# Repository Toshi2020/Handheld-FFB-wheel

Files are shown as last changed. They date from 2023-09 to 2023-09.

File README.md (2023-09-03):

# Handheld-FFB-wheel  
# ハンドヘルド型FFB(フォースフィードバック)ハンドルコントローラー  

**●ここには詳細を置きます。概要はこちら↓に記述しました。**  
https://minkara.carview.co.jp/userid/3336538/blog/47191094/

**動作の状況の動画はこちら。**  
https://youtu.be/O-O_uvx_jfw 

**●初めに**  
　PCで車のゲームをプレイするとき、ゲームパッドではハンドル操作感が乏しいので運転が難しく、かといって机にFFBハンドルコントローラーを据え付けると使わないときに邪魔です。そこで気が向いた時だけ手軽に接続できるようにハンドヘルド型FFBハンドルコントローラーを作ってみました。  
外観

**●主な部品**  
①DCモーター: タミヤ ソーラーモーター02 Amazon購入価格 721円  
②Arduino Pro Micro: AliExpress購入価格 568円  
③モータードライバー: BD6211F-E2 秋月購入価格 110円  
④ピッチ変換基板: P-05154 秋月購入価格 100円/9枚 単価11円  
⑤ショットキーバリアダイオード: 1S4 秋月購入価格 140円/10本 単価14円  
⑥ツェナーダイオード: Amazonでアソートキット 1200円/200本 単価6円  
⑦ボリューム: Bカーブ 手持ち品ですが秋月では60円  
⑧タクトスイッチ: 昔秋月で購入した手持ち品ですが今は 300円/10個 単価30円x3  
⑨分割ロングピンソケット: 秋月購入価格 80円  
⑩ジョイスティック: Amazon購入価格 799円/5個 単価160円  
その他は手持ちから流用ですが全部購入してもトータルで2,000円弱かと思います。(3Dプリンタのフィラメント代が別途必要です。)  
パーツ

**●ハードウェア**  
回路図2

メインボード

・マイコンボードとしてArduino Pro Microを使います。PC用ゲームコントローラとして使うためにはArduino NANOやArduino Pro Miniではダメなので注意が必要です。今回AliexpressからUSB Type-Cコネクタの物を調達しました。  
・Arduinoは他に転用するかもしれないので秋月の分割ロングピンソケットを介して万能基板に取り付けて、ずれないように4隅をホットボンドで固定しています。またUSBコネクタ部分もホットボンドで補強しています。それとArduinoのピンは付属品ではなく秋月の細ピンヘッダ―を使っています。  
メインボード2

・USB給電だけで動かしたかったので、反力用のモーターとしては小電流で低回転のタミヤのソーラーモーター02を使います。このモーター、ネットで調べたのですが詳細スペックがわからず、おそらくAmazonで売られているRF-500TB-18280という型番の物ではないかと思います。タミヤで出している物は価格が少し高いのですがM2.5(?)の取り付けネジとピニオンギアが同梱されているのがメリットです。  
・モータードライバは秋月で購入したBD6211F-E2を同じく秋月のピッチ変更基板を使って組んでいます。  
・モーターを外部から回転させることになるので逆起電力により、モーターの回転と同方向に回すと供給電圧以上の電圧が発生し、逆方向に回すとストール電流以上の電流が流れるはずです(実測はしていないのですが)。マイコンやPCのUSB側に過電圧がかからないように1Aのショットキーダイオード1S4を介してモーターとドライバに給電しています。またドライバの定格電圧が7Vなので、保護のために5.6V 1Wのツェナーダイオードを入れています。電源ラインには100μの電解コンデンサを入れて電圧ドロップに対応したつもりです。  
・ボリュームは手持ちの関係でB型50kΩを使いましたがB型なら1k～100kΩの範囲で大丈夫だと思います。10kΩが良いかと思います。  
・ジョイスティックは、当初前後に倒してアクセル/ブレーキ、左右に倒してスイッチ(シフトアップ/シフトダウンに割り当て)としたのですが、操作に難があることがわかりY軸のみを使うことにしました。前後に倒したつもりでも左右に動いてしまうので、アクセル/ブレーキの微妙な調整が難しいのです。  
・パーツやケースの上下の固定はM3の6mmのビスを使用します。  
・モーターのシャフトには10歯のピニオンギアを使います。  
・モーターとボリュームは振動するのでネジロック剤を併用して取り付けています。  
・モーター、ボリューム、スイッチは万能基板とXHコネクタで接続しています。何度か抜き差ししているうちにコネクタの付け根が断線してしまったのでホットボンドで補強しています。  
内部

**●ソフトウェア**  
・ArduinoでFFBホイールコントローラーを実現するためのソフトがGitHubにいくつかアップされているのですが、今回使用したもの以外ではAssettoCorsaでCPU使用率が99%を超えてシミュレーションが劇遅になってしまい使えませんでした。  
・ビルドするためにはこちらのAFFBWheel↓の、  
  https://github.com/vsulako/AFFBWheel  
  AFFBWheelフォルダから、  
  以下のファイル以外のファイルをMyAFFBWheelフォルダにコピーします。  
    AFFBWheel.ino, bb_i2c.cpp, bb_i2c.h, motor.cpp, motor.h, multiturn.cpp, multiturn.h   
・Arduino IDE 1.8.19以上でボードタイプはArduino Leonardoを選択してビルドします。  
・ビルドするとコントロールパネルのデバイスとプリンターにArduino Leonardoというゲームデバイスが出現します。  
・オリジナルのAFFBWheelではステア入力デバイスは光学エンコーダーを使うようになっていますが、ArduinoのA/Dに置き換えています。またオリジナルはEEPに調整用の値を書き込んで(設定用の汎用アプリがあるようです)細かい調整ができるようですが、今回は端折っています。  
・オリジナルを解析しつくしたわけではないので間違っているところもあるかもしれません。  
・オリジナルでは8軸のアナログと32個のボタン入力ができるのですが、今回はアナログ4軸と4ボタンのみ使っています。アナログはステア、アクセル、ブレーキ、クラッチです。  
・ステア入力はArduinoのA/Dが10bit分解能なので、値としては0～1023までしかとることができません。これでは1LSBの変化でステアがカクカク動いて使い物になりません。そこでA/Dの読みを100倍した値をフィルタに入れて見かけ上の分解能を上げることにしました。このフィルタは、ステアを動かさないときには重く、動かしているときには軽くすることで、安定性と応答性の両立を狙っています。  
・クラッチに関してはSW1を割り当てるという前提で、ボタンだけでなくアナログ軸にも出力を行うようにしています。AssettoCorsaはクラッチはアナログ軸にしか割り当てができないようなので。アナログ軸の方は、SW1を押した時にスパッと切れて離すと0.5秒かけて戻るようにしています。  
・また、クラッチを踏んでいる間はブレーキを変化させないようにしています。これはヒールアンドトゥの操作を可能とするためです。(そんなことするか？はわかりませんけどね)  
・モーターに指示するPWM値は、ストール時に0.3[A]程度となるように最大値Fmaxを180としています。これはUSB2.0の最大電流が0.5[A]なので、それに対して逆起電力分を考慮した物です。  
・減速が1段のせいか、ステアから手を放した時のフォースによる戻り回転速度が速すぎるようで、ステアが行き過ぎて戻ってを繰り返すことがあったので、ステア回転速度に反比例してフォースを減少させるダンピング制御を入れました。  
・モーターには微小なPWMを与えても回転しない、いわゆるデッドゾーンがあります。デッドゾーンがあると、微小なフォースではステアが動かずに、フォースが徐々に上がった時にカクンと動き始めることになり、車の直進安定性が悪化します。そこでフォースをPWM出力する際にデッドゾーンを除去する処理を入れています。  
・通電時にステアをほぼ中央に戻す動きを行うようにしました。  
・SW1,3,4を押しながら通電すると耐久テストモードとなります。目標ステア角を徐々に増やしてMAXフォースで連続して左右に振ります。100サイクル回した限り問題ありませんでした。このとき非接触温度計でモーター温度45℃、ボード上のCPU温度50℃、電圧レギュレータ温度60℃でした。レギュレータが一番発熱するとは意外でした。またモーターが反転するときにボード上のLEDが一瞬暗くなるので電源ラインの電解コンデンサの容量はもっと増やした方が良いかと思います。  
・SW3,4を押しながら通電するとフォーステストモードとなります。ArduinoIDEのシリアルモニタでフォースとして-255～255の数値を送ると直接PWM出力します。この時デッドゾーン除去の処理も入ります。  

**●筐体について**  
・実はこのケースは3作目で、ステアの回転軸を30°手前に傾けています。前作は回転軸が横向きでした。昔ネジコンというコントローラーがあったのと、ラジコン用のプロポを意識したのですが、ボリュームの回転角300°を回すには横向きでは人体の構造上無理があることがわかりました。30°傾いていると肘の関節の回転を使えるので持ち替えずに回しきることができます。私はどちらも触ったことがないのですが、おそらくネジコンやプロポの回転範囲は狭いのだと思います。  
平面図

**●3Dデータ＆組付けについて**  
・使用するパーツによって修正が必要かもしれないので(特にタクトスイッチは昔に購入した物なので今の物とはサイズが違うかもです)STLだけでなくFusion360のファイルも入れておきます。"全パーツ.f3d"です。  
・スペーサーというモデルはさらに小型のボリュームを使う際に、シャフトが短い分を埋めるために使います。  
・ジョイスティックは、シャフトを±30°くらい傾けられるのですが、リニアな変化が得られるのは±22°くらいです。±30°倒せるようにするとリニアな領域が狭くてほとんどスイッチ的な使い方になってしまうので、ケースの上蓋の溝で±24°に制限をかけています。  
・ジョイスティックのノブは、スカート部分を切り取って使います。
ジョイスティックノブ

・スライサーはUltimaker-Curaを使っています。フィラメントはメインギア以外は汎用/PLAでStandard Quality - 0.2mmでインフィル密度20%、印刷は0.4mmノズルです。  
・サポートを外しやすいように、サポートオーバーハング角度は70°、サポート密度は5.0%としました。  
・メインギアだけはSuper Quality - 0.12mmでインフィル100%で印刷しました。  
・メインギアのマテリアルは最初PLAで印刷したのですがゴリゴリ感が気になり、もう少し柔軟性のあるPETGにしたところ改善が見られました。それではという事でさらに柔軟性のあるTPUで印刷したところさらに改善が見られ、さらに回転方向にバネ性を持たせる構造にすることでも改善が感じられました。メカ設計のプロから見たらとんでもないことかもしれませんが、私は素人なのでやれちゃいます。  
・メインギアのUltimaker-Curaのフィラメント設定は汎用/TPU 95Aです。  
・一応歯面にシリコングリスを薄く塗布してみましたが、効果は感じられませんでした。  
・手持ちのPETGフィラメントの線径が細いのだと思いますが、PLAと同じデータだとスカスカになってしまったので若干サイズを調整しています。  
・TPUギアって耐久的にどうかなと思ったので、ソフトで耐久試験ができるようにしました。  
・ギアの印刷で、1周に1か所スタート点ができるのですが、その部分の歯のサイズが少し大きくなり、ピニオンギアとのかみ合わせに滑らかさが欠けます。ボリュームの回転角が300°なので、ギアのスタート点にマーキングをして、その歯を避けて組み付ける必要があります。  
ギア印刷

ギアマーキング

・印刷前にレベリングをちゃんと調整しておかないといけません。ノズルとベッドとの隙間が狭すぎるとケースのあわせ面のリブの溝の幅が狭まってしまって組めなくなるので注意です。

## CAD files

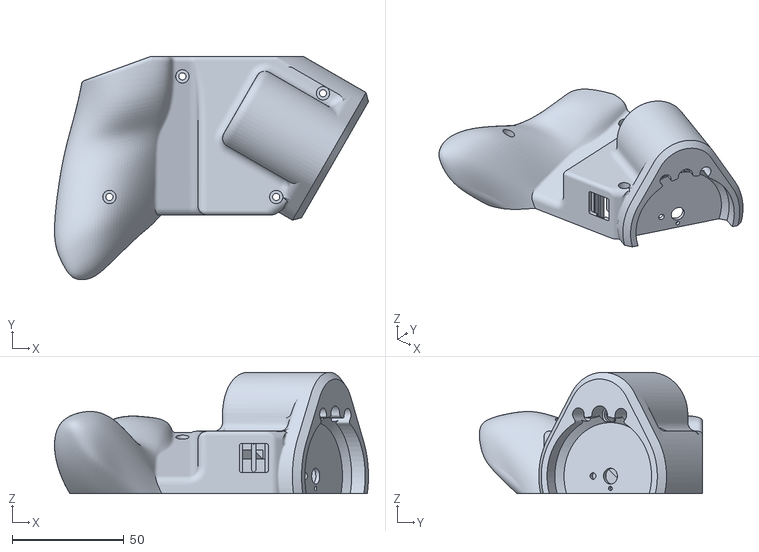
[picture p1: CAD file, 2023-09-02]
3Ddata/ゲームパッド下.stl
140.6 x 100.1 x 54.4

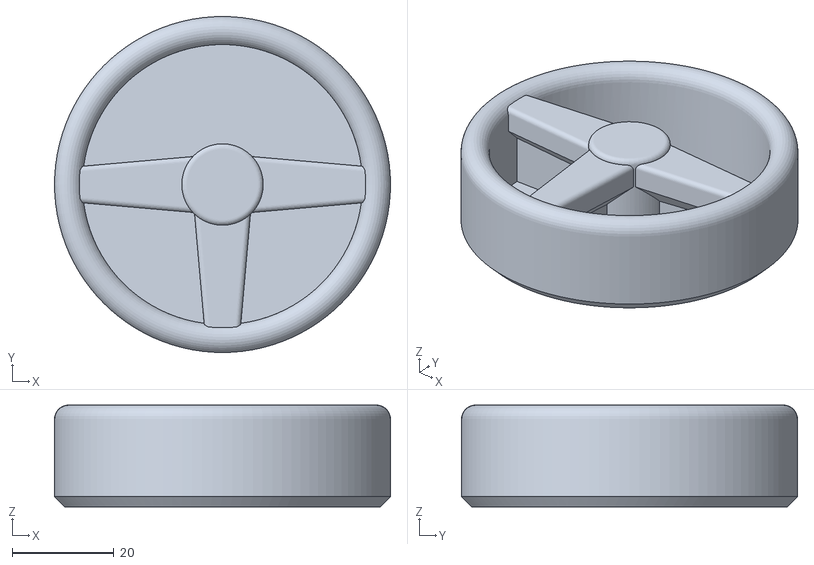
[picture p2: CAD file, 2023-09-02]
3Ddata/ステアリング.stl
66.0 x 66.0 x 20.0

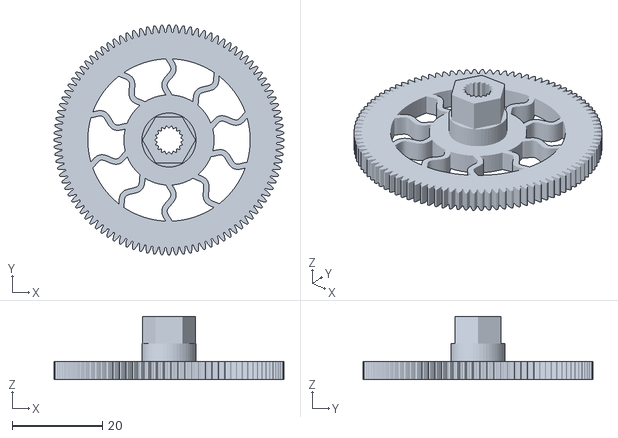
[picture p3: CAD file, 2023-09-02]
3Ddata/メインギア(バックラッシュ0.1mm)TPU.stl
51.0 x 51.0 x 14.0

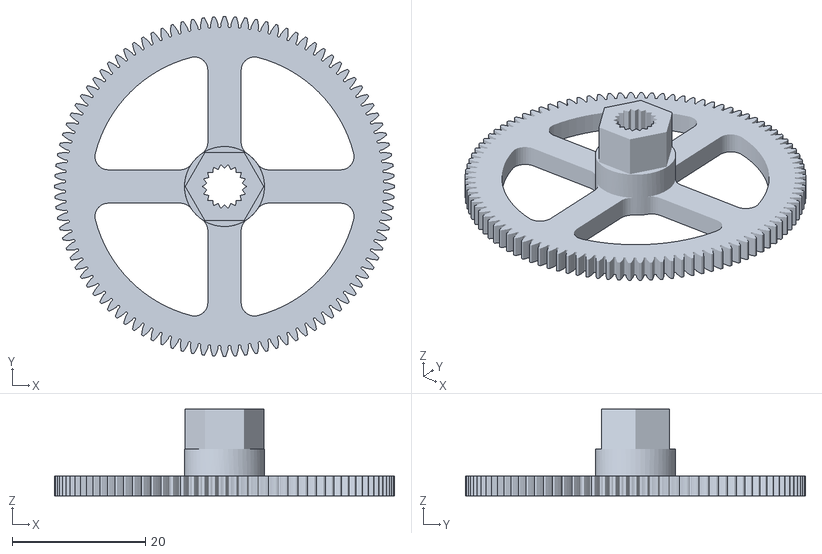
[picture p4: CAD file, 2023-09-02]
3Ddata/メインギア(バックラッシュ0.1mm)PETG.stl
51.0 x 51.0 x 13.0

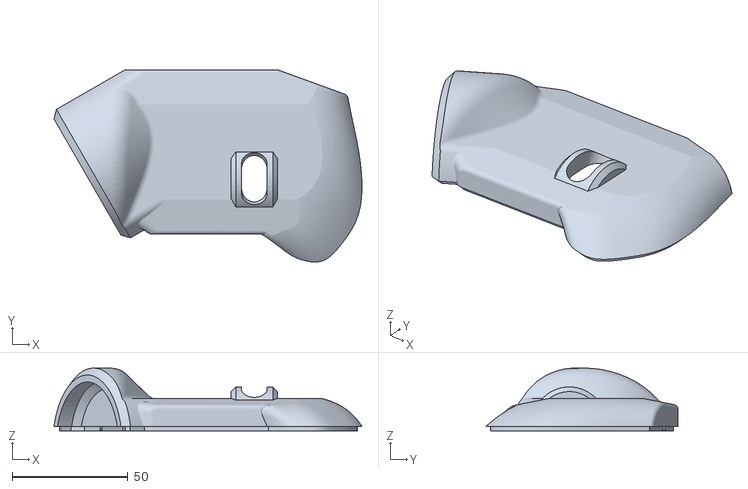
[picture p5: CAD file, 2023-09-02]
3Ddata/ゲームパッド上.stl
133.1 x 83.0 x 27.1

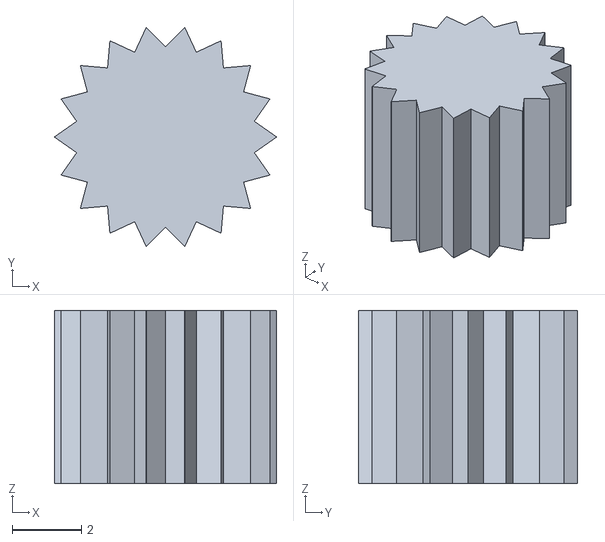
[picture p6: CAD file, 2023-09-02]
3Ddata/スペーサー.stl
6.40 x 6.30 x 5.00

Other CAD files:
3Ddata/メインギア(バックラッシュ0.1mm).stl
3Ddata/全パーツ.f3d

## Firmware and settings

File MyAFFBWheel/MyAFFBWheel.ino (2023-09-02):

/*****************************************************************************
*
*	MyAFFBWheel.ino -- FFBステアリング(Arduino Pro Micro専用)
*
*	ビルドの方法
*	・こちらのAFFBWheel↓の、
*	　https://github.com/vsulako/AFFBWheel
*	　AFFBWheelフォルダから、
*	　以下のファイル以外のファイルをこのフォルダにコピーする
*		AFFBWheel.ino, bb_i2c.cpp, bb_i2c.h, motor.cpp, motor.h,
*		multiturn.cpp, multiturn.h, 
*	・Arduino IDE 1.8.19以上でボードタイプはArduino Leonardoを選択してビルド
*
*	rev1.0	2023/08/20	initial revision by	Toshi
*
*****************************************************************************/

#include "wheel.h"
#include "settings.h"

// Arduino ピン設定
#define PIN_AY A2		// Joystick Y
#define PIN_SW2 A1		// JoystickのプッシュSW
#define PIN_STR A0		// ステア
#define PIN_SW3 4		// タクトSW3
#define PIN_SW4 5		// タクトSW4
#define PIN_SW1 8		// タクトSW1
#define PIN_CW 9		// モーター正転
#define PIN_CCW 10		// モーター逆転

Wheel_ wheel;			// ステアリングホイールオブジェクト
SettingsData settings;	// セッティングデータ構造体
bool fReqCenter;		// ステアリングをセンターに戻す要求
unsigned long LastTime;	// ループ時間計測用
int bug;
bool fEnduranceTest, fForceTest;
int RxForce;			// 受信したフォース
int Fmax = 255;			// 最大フォース

// プロトタイプ宣言
void PwmForce(int force, int ad_steer, int velocity);
int EnduranceTestForce(int ad_steer);
int MoveForce(bool* frun, int target, int ad_steer);
long map2(long x, long in_min, long in_max, long out_min, long out_max);
float mapf(float x, float in_min, float in_max, float out_min, float out_max);
void Filter(float* filt, float dat, float fact);
void AddOnTime(bool flag, int* ontime);
/*----------------------------------------------------------------------------
	セットアップ
----------------------------------------------------------------------------*/
void setup()
{
	// ピンモードの設定
	pinMode(PIN_SW1, INPUT_PULLUP);
	pinMode(PIN_SW2, INPUT_PULLUP);
	pinMode(PIN_SW3, INPUT_PULLUP);
	pinMode(PIN_SW4, INPUT_PULLUP);
	pinMode(PIN_CW, OUTPUT);
	pinMode(PIN_CCW, OUTPUT);

	// Timer1のPWM周波数を490Hz→31.25kHzに変更(HブリッジBD6211Fは20kHz以上要)
	TCCR1B &= B11111000;
	TCCR1B |= B00000001;

	Serial.begin(115200);	// デバッグ用ハードウェアシリアル

	// FFBセッティング
	FfbSetting();

	// テストモードか？
	fEnduranceTest = !digitalRead(PIN_SW1) && !digitalRead(PIN_SW3) &&
					 !digitalRead(PIN_SW4);
	fForceTest = !digitalRead(PIN_SW3) && !digitalRead(PIN_SW4);

	if (!fEnduranceTest && !fForceTest)	// 通常モードなら
	{
		// ステアリングをセンターに戻す要求を出す
		MoveForce(&fReqCenter, 512, 512);	// 初期化
		fReqCenter = true;
		Fmax = 180;		// PWM最大指示値
						// (USB2.0の規格では最大電流が0.5[A]なので、
						// ストール電流を0.3[A]程度にしておくのが良いと思う)
						// USBモニタによる実測
						// 255 = 0.52[A]
						// 200 = 0.49[A]
						// 180 = 0.33[A]
	}

	LastTime = millis();
}
/*----------------------------------------------------------------------------
	メインループ
----------------------------------------------------------------------------*/
#define ST_MAX 10230// ステアリング最大指示値
					// ↑これでおおむねint16のフルスケールになるようだ
#define FILTMIN 0.5	// ステアフィルタ定数(一番軽い時)
#define FILTMAX 0.01// ステアフィルタ定数(一番重い時)
#define SDELTA 500	// ステアフィルタが一番軽くなる時のステア速度
#define ACMAX 1000	// アクセルA/D最大値
#define ACMIN 510	// アクセルA/D最小値
#define BKMAX 490	// ブレーキA/D最大値
#define BKMIN 0		// ブレーキA/D最小値
#define DAMPC 0.2	// ステアダンピング係数(大きくするとダンピング大)
#define DPV 10		// ステアダンピングを効かせる最低回転速度
#define CDELTA 204	// 100ms当たりのクラッチ戻し量
#define FDEADMIN 30	// モーターが回らないPWM値
void loop()
{
	bool fsw1, fsw2, fsw3, fsw4;
	int ad_y, ad_steer;
	int accel, brake, steer;
	int ffb, force, velocity;
	static float steer_filt;
	static uint32_t switchs, switchsz;
	static int dcount, clutch;
	static float filtc = FILTMIN;
	float damp;

	// A/Dを読む
	ad_y = analogRead(PIN_AY);		// Joystick Y
	ad_steer = analogRead(PIN_STR);	// ステア

	// SWを読む
	fsw1 = !digitalRead(PIN_SW1);
	fsw2 = !digitalRead(PIN_SW2);
	fsw3 = !digitalRead(PIN_SW3);
	fsw4 = !digitalRead(PIN_SW4);
	switchs = fsw4 << 3 | fsw3 << 2 | fsw2 << 1 | fsw1;	// SW情報を束ねる

	// ステアのA/D値をを100倍した値をフィルタリング
	// (10bitのA/Dでは分解能が不足なので疑似的にビットを増やす意味もある)
	Filter(&steer_filt, (float)ad_steer * 100.0, filtc);

	// アクセル、ブレーキ、ステア量を変換する
	accel = map(ad_y, ACMIN, ACMAX, 0, 1023);
	brake = map(ad_y, BKMAX, BKMIN, 0, 1023);
	steer = map((long)steer_filt, 0, 102300, -ST_MAX, ST_MAX);

	// ホイールにデータを渡す
	wheel.axisWheel->setValue(steer);
	wheel.analogAxes[AXIS_ACC]->setValue(accel);
	// SW1をクラッチに割り当てる前提
	if (fsw1)
	{
		clutch = 1023;	// SWオンで目いっぱい踏んでいることにする
	}
	else
	{
		// クラッチを踏んでいるときはブレーキホールドとする
		// すなわちブレーキを更新はクラッチオフの時のみとする
		// これはヒール＆トゥを実現するため(使わないかも)
		wheel.analogAxes[AXIS_BRAKE]->setValue(brake);
	}
	// クラッチはアナログ軸にも同時に出力する
	// ゲーム側でSWとどちらでも選択可能にするため
	wheel.analogAxes[AXIS_CLUTCH]->setValue(clutch);

	// SWのチャタリング除去(デバウンス処理)
	if (switchsz != switchs)	// SWに変化があったら
	{
		dcount = 0;				// カウンタ初期化
		switchsz = switchs;		// 変化した時のSWの状態を保持
	}
	else
	{
		if (dcount < settings.debounce)	// 規定時間に達するまでは
		{
			dcount++;	// カウンタを+1するだけでSW情報を伝えない
		}
		else
		{
			wheel.buttons = switchs;	// ホイールにSW情報を伝える
		}
	}
	// ホイール指示アップデート
	wheel.update();
	velocity = wheel.axisWheel->velocity;	// ステア回転速度を取得

	// ここで次回のためにステアのフィルタ定数を決定しておく
	// (フィルタはステア速度が遅い時には重く、速い時には軽くする)
	filtc = mapf((float)abs(velocity), 0, SDELTA, FILTMAX, FILTMIN);

	if (fEnduranceTest)	// 耐久試験モードなら
	{
		force = EnduranceTestForce(ad_steer);	// 耐久試験用のフォースを得る
	}
	else if (fForceTest)	// フォーステストモードなら
	{
		RxData();			// データ受信
		force = RxForce;	// 受信したフォースを出力
	}
	else
	{
		if (fReqCenter)	// センタリング要求中なら
		{
			force = MoveForce(&fReqCenter, 512, ad_steer);	// センタリング
		}
		else	// 通常動作中なら
		{
			// ホイールからFFBデータを受ける
			ffb = wheel.ffbEngine.calculateForce(wheel.axisWheel);

			// モーターによるステア回転が速すぎるのでダンピングする
			damp = (float)abs(velocity) * DAMPC;// 速度の係数倍を分母に
			if (damp != 0.0)	// 0割防止
			{
				damp = 100.0 / damp;	// 速度に反比例
				damp = min(1.0, damp);	// 0～1.0 1.0ならダンピング効果なし
				// FFBによりステアが回転していたら
				if ((velocity <= -DPV && ffb > 0) ||
					(velocity >= DPV && ffb < 0))
				{
					// 速度に反比例してFFBを減少
					ffb = (int)((float)ffb * damp);
				}
			}
			// モーターの範囲内に変換する
			force = map(ffb, -16383, 16383,
							-Fmax + FDEADMIN, Fmax - FDEADMIN);
		}
	}
	// フォースをPWM出力
	PwmForce(force, ad_steer, velocity);

	// 定時処理
	if (millis() - LastTime >= 100L)	// 100[ms]
	{
		LastTime = millis();

		if (clutch)
		{
			clutch -= CDELTA;			// クラッチを徐々に離す
			clutch = max(0, clutch);	// 0以上
		}

		// ↓デバッグ時にコメントを外す
//		Serial.println(ad_y);
//		Serial.println(ad_steer);
//		Serial.println(steer);
//		Serial.println(wheel.axisWheel->velocity);
//		Serial.println(damp);
//		Serial.println(ffb);
//		Serial.println(force);
//		Serial.println(bug);
	}
}
/*----------------------------------------------------------------------------
	耐久試験(左右にステップ駆動)用のフォースを得る
	書式 int ret = EnduranceTestForce(int ad_steer);

	int ret;		フォース -Fmax～+Fmax
	int ad_steer;	ステアA/D値 0～1023
----------------------------------------------------------------------------*/
#define STEPDELTA 5	// A/D幅
int EnduranceTestForce(int ad_steer)
{
	static int steps = STEPDELTA, force = 255;
	static bool fup = true;
	int upper, lower;
	static long bcount;

	upper = 512 + steps;
	lower = 512 - steps;
	if (fup && ad_steer >= upper)	// ステアが右回転して位置に達した？
	{
		force = Fmax;	// ステア左回転に転じる
		fup = false;
	}
	else if (!fup && ad_steer <= lower)	// ステアが左回転して位置に達した？
	{
		force = -Fmax;	// ステア右回転に転じる
		fup = true;
		steps += STEPDELTA;
		if (steps >= 512)	// 最後まで行った？
		{
			steps = STEPDELTA;// 最初に戻る
			bcount++;
			Serial.println(bcount);	// 回数を表示
		}
	}
	return force;
}
/*----------------------------------------------------------------------------
	位置制御用のフォースを得る
	書式 ret = MoveForce(bool* frun, int target, int ad_steer);

	int ret;		フォース -255～+255 正の時ステアが左に回転する
	bool* frun;		作動要求フラグ
	int target;		目標A/D位置0～1023
	int ad_steer;	ステアA/D値 0～1023
----------------------------------------------------------------------------*/
#define PGAIN 0.3	// 比例ゲイン
#define IGAIN 0.1	// 積分ゲイン
#define ERRRANGE 20	// 終了判定A/D範囲
#define ENDTIME 50	// 終了判定時間5[s]x10
#define FSTIME 100	// 強制終了時間10[s]x10
int MoveForce(bool* frun, int target, int ad_steer)
{
	static float err, i;
	static int force, runtime, endtime;
	static long lasttime;

	if (!*frun)	// 初期化要求？
	{
		i = 0.0;
		force = runtime = endtime = 0;
		lasttime = millis();
		return 0;
	}
	if (millis() - lasttime >= 100L)	// 100ms
	{
		lasttime = millis();
		AddOnTime(*frun, &runtime);			// 稼働時間

		err = (float)(ad_steer - target);	// 位置偏差
		if (abs(force) < Fmax)				// サチってなければ
		{
			if (runtime >= 10)	// 最初の1秒はI項の累積しない
			{
				i += (float)err / 10.0;			// I項累積
			}
		}
		// PI
		force = (int)(err * PGAIN + i * IGAIN);
		force = constrain(force, -Fmax, Fmax);

		// エラーが範囲内に入っている時間
		AddOnTime(abs(err) < ERRRANGE, &endtime);
		// 強制終了時間を経過したか、偏差が範囲内に入っている時間が規定以上？
		if (runtime >= FSTIME || endtime >= ENDTIME)
		{
			*frun = false;		// 制御終了
			i = 0.0;
			force = runtime = endtime = 0;
			if (target == 512)	// センターへの指示だった場合
			{
				wheel.axisWheel->center();	// センターに戻ったことを伝える
			}
		}
//		Serial.print(err);
//		Serial.print(", ");
//		Serial.print(i);
//		Serial.print(", ");
//		Serial.println(force);
	}
	return force;
}
/*----------------------------------------------------------------------------
	フォースをPWM出力
	書式 void PwmForce(int force, int ad_steer, int velocity);

	int force;		フォース -Fmax～+Fmax 正の時ステアが左に回転する
	int ad_steer;	ステアA/D値 0～1023
	int velocity;	ステア速度
----------------------------------------------------------------------------*/
#define FDEADMAX 60	// モーターが回り始めるPWM値
#define FDELTA 0.1	// オフセット増加幅
#define FDEADV 30	// 回転とみなす速度
void PwmForce(int force, int ad_steer, int velocity)
{
	static float offset;
	static bool fbegin;
	static int forcez;

	//*** デッドゾーン除去 ***
	// (回転が始まらない限りオフセットをFDEADMINからFDEADMAXまで増やす)

	// 指示フォースが0以下から正に変化した？
	if (forcez <= 0 && force > 0)
	{
		offset = FDEADMIN;	// 初期オフセットを設定
		fbegin = true;
	}
	// 指示フォースが0以上から負に変化した？
	else if (forcez >= 0 && force < 0)
	{
		offset = -FDEADMIN;	// 初期オフセットを設定
		fbegin = true;
	}
	// 指示フォースが0？
	else if (force == 0)
	{
		offset = 0.0;	// オフセットなし
		fbegin = false;
	}
	forcez = force;
	// フォースが正
	if (fbegin && offset > 0)
	{
		// ステアが左回転したかオフセットが十分大きくなった？
		if (velocity < -FDEADV || offset >= FDEADMAX)
		{
			fbegin = false;	// これ以上は増やさない
		}
		else	// ステアが左回転していないなら
		{
			offset += FDELTA;	// オフセット量を少し増やす
		}
	}
	// フォースが負
	else if (fbegin && offset < 0)
	{
		// ステアが右回転したかオフセットが十分小さくなった？
		if (velocity > FDEADV || offset <= -FDEADMAX)
		{
			fbegin = false;	// これ以上は減らさない
		}
		else	// ステアが右回転していないなら
		{
			offset -= FDELTA;	// オフセット量を少し減らす
		}
	}
	force += (int)offset;	// デッドゾーン分を上乗せ
	force = constrain(force, -Fmax, Fmax);
	if (force > 0)
	{
		// モーター右回転→ステア左回転
		digitalWrite(PIN_CCW, LOW);
		if (ad_steer > 2)				// 左に回り切っていないなら
		{
			analogWrite(PIN_CW, force);	// ステア左回転
		}
		else
		{
			digitalWrite(PIN_CW, LOW);	// フェイルセーフで停止
		}
	}
	else if (force < 0)
	{
		// モーター左回転→ステア右回転
		digitalWrite(PIN_CW, LOW);
		if (ad_steer < 1021)			// 右に回り切っていないなら
		{
			analogWrite(PIN_CCW, -force);// ステア右回転
		}
		else
		{
			digitalWrite(PIN_CCW, LOW);	// フェイルセーフで停止
		}
	}
	else
	{
		// ブレーキ
		digitalWrite(PIN_CW, HIGH);
		digitalWrite(PIN_CCW, HIGH);
	}
}
/*----------------------------------------------------------------------------
	データ受信
----------------------------------------------------------------------------*/
#define BUFMAX 64	// 受信バッファサイズ
void RxData()
{
	char c, *p;
	static char rxbuff[BUFMAX];	// 受信バッファ
	static char pbuff;			// バッファポインタ
	int count, i;
	int rxdata;

	while (Serial.available() > 0)	// 文字を受信していれば
	{
		c = Serial.read();			// 1文字受信
		if (pbuff < BUFMAX - 2)		// バッファに余裕があるなら
		{
			rxbuff[pbuff++] = c;	// 格納
			if (c == '\n' && pbuff > 1)	// 行末か？
			{
				rxbuff[pbuff - 1] = '\0';// 文字列をターミネート
				pbuff = 0;			// ポインタを先頭に
				Serial.println(rxbuff);
				RxForce = atoi(rxbuff);	// 文字→数値変換
			}
		}
		else	// バッファフルなら
		{
			pbuff = 0;	// ポインタを先頭に
		}
	}
}
/*----------------------------------------------------------------------------
	最大最少リミット付きmap関数()
----------------------------------------------------------------------------*/
long map2(long x, long in_min, long in_max, long out_min, long out_max)
{
	long ret;

	ret = map(x, in_min, in_max, out_min, out_max);
	ret = constrain(ret, out_min, out_max);
	return ret;
}
/*----------------------------------------------------------------------------
	最大最少リミット付きmap関数()float版
----------------------------------------------------------------------------*/
float mapf(float x, float in_min, float in_max, float out_min, float out_max)
{
	float ret;

	ret = (x - in_min) * (out_max - out_min) / (in_max - in_min) + out_min;
	ret = constrain(ret, out_min, out_max);
	return ret;
}
/*----------------------------------------------------------------------------
	フィルタ
	書式 void Filter(float* filt, float dat, float fact);

	float filt;		入力(1サンプル前)→出力
	float dat;		入力(今回)
	float fact;		フィルタ定数
----------------------------------------------------------------------------*/
void Filter(float* filt, float dat, float fact)
{
	*filt = (1.0 - fact) * *filt + fact * dat;
}
/*----------------------------------------------------------------------------
	フラグのオン時間の累積
	書式 void AddOnTime(bool flag, int* ontime)

	bool flag;		フラグ
	int* ontime;	オン時間
----------------------------------------------------------------------------*/
#define	TIMEMAX 30000
void AddOnTime(bool flag, int* ontime)
{
	if (flag)							// オンしてるなら
	{
		if (*ontime < TIMEMAX)
		{
			(*ontime)++;				// オン時間++
		}
	}
	else
	{
		*ontime = 0;
	}
}
/*----------------------------------------------------------------------------
	FFBセッティング(オリジナルではEEPから読み出すがここでは直接セット)
----------------------------------------------------------------------------*/
void FfbSetting()
{
	uint8_t i;

	// 各ゲイン 1024で100[%]
	settings.gain[GAIN_TOTAL] = 1024;
	settings.gain[GAIN_CONSTANT] = 1024;
	settings.gain[GAIN_RAMP] = 1024;
	settings.gain[GAIN_SQUARE] = 1024;
	settings.gain[GAIN_SINE] = 1024;
	settings.gain[GAIN_TRIANGLE] = 1024;
	settings.gain[GAIN_SAWTOOTHDOWN] = 1024;
	settings.gain[GAIN_SAWTOOTHUP] = 1024;
	settings.gain[GAIN_SPRING] = 1024;
	settings.gain[GAIN_DAMPER] = 512;	// 100%だとゴリゴリする
	settings.gain[GAIN_INERTIA] = 1024;
	settings.gain[GAIN_FRICTION] = 1024;
	settings.gain[GAIN_ENDSTOP] = 1024;

	settings.centerButton = -1; // no center button

	settings.debounce = 10;	// SWのチャタリング除去をしないなら0
	settings.minForce = 0;
	settings.maxForce = 16383;
	settings.cutForce = 16383;

	settings.endstopOffset = DEFAULT_ENDSTOP_OFFSET;
	settings.endstopWidth = DEFAULT_ENDSTOP_WIDTH;
  
	for (i = 0; i < 7; i++)
	{
		wheel.analogAxes[i]->setLimits(0, 1023);
		wheel.analogAxes[i]->setCenter(-32768);	// no center
		if (!wheel.analogAxes[i]->autoCenter)
		{
		   wheel.analogAxes[i]->setDZ(0);
		}

		wheel.analogAxes[i]->bitTrim = 0;
		wheel.analogAxes[i]->outputDisabled = 0;
	}
	wheel.axisWheel->setRange(WHEEL_RANGE_DEFAULT);
	wheel.ffbEngine.maxVelocityDamperC = 16384.0 / DEFAULT_MAX_VELOCITY;
	wheel.ffbEngine.maxVelocityFrictionC = 16384.0 / DEFAULT_MAX_VELOCITY;
	wheel.ffbEngine.maxAccelerationInertiaC = 16384.0 / 
											DEFAULT_MAX_ACCELERATION;
}
/*** end of "MyAFFBWheel.ino" ***/
